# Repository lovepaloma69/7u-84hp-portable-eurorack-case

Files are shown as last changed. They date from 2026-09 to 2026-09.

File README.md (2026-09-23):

# Eurorack 84HP / 7U — Removable Mounting System

Custom, 3D-printed mounting hardware that holds a **7U × 84HP Eurorack frame**
(~440 mm × 311 mm) removably inside a transport / tool case — and, in progress,
inside a wooden rack case. Everything is modeled parametrically in **OpenSCAD**
and verified against the real frame geometry with **trimesh** cross-sections
(no "just print and see" — parts are checked against measured geometry first).

**Designed to fit:** the **RGC Cases 170/48H184** polypropylene case —
<https://rgcases.com/cases-in-polypropylene/170-48h184.html> — which this whole
mounting system is dimensioned around.

> This project is an **accessory** built on top of **kowend's** open Eurorack
> case design (see [Credits & Source](#credits--source)). This repository
> contains **only my own original work** — brackets, rails/profiles, spacer,
> snap latch, clip and holders. It does **not** redistribute kowend's STL / CAD
> / image files; get those from the original project.

## Components

| File | Part | Notes |
|---|---|---|
| `openscad/bracket.scad` | Rail bracket, split into 3 printable segments | References kowend's body STL at build time (see [Setup](#setup--build)) — the STL is not shipped here |
| `openscad/case_holder.scad` | Short-wall rails/profiles, snap latch, flex clip | Firm side (rigid snap, wide neck) + release side (support-only + flex-arm profiles) |
| `openscad/spacer.scad` | Long-wall spacer | 100 × 11 × 11 mm strip; fills the gap between the cover underside and the rail |
| `openscad/wood_holder.scad` | Wooden-case holder | Work in progress |
| `openscad/assembly_explainer.scad`, `openscad/install_context_preview.scad` | Assembly / install visualizations | |
| `analysis/*.py` | Geometry analysis (trimesh + matplotlib) | Cross-sections & measurements used to fit the parts |

## Printed parts (`openscad/export/`)

Ready-to-print STLs for the **original** parts:
`profil*.stl`, `spacer.stl`, `wood_holder.stl`, `flex_clip.stl`.

The **bracket segments** are derived from kowend's model and are therefore
**not** included — regenerate them from `bracket.scad` after obtaining kowend's
STL (see below).

## Setup / Build

1. Install **OpenSCAD** (tested with 2021.01).
2. `bracket.scad` imports kowend's body geometry. Download the corresponding
   STL from the [original project](https://github.com/kowend/Eurorack_84HP_7U_case)
   and place it at:
   ```
   printables/variant1/variant1_body0_local.stl
   ```
3. Export a part, e.g. the toothed profile:
   ```bash
   openscad -D render_part=1 -D with_teeth=true \
     -o export/profil_zaehne.stl case_holder.scad
   ```
4. Verify a part's real dimensions (optional):
   ```bash
   python -c "import trimesh; m=trimesh.load('export/spacer.stl'); print(m.bounds[1]-m.bounds[0])"
   ```

## Print settings

- **Printer:** Bambu Lab A1 Mini
- **Material:** PETG
- **Orientation matters** for the flexing/snap features: the snap latch uses a
  *rigid* arm with a wide neck (push-to-open by tilting the frame flange), and
  the flex clip prints **upright** so it flexes in-plane rather than across
  layer lines. Teeth print flat (across layers) for strength.

## Contributing

**Collaboration and further development of the design are explicitly welcome!**
Feel free to open an [issue](../../issues) for ideas, problems or measurements,
or send a [pull request](../../pulls) with improvements, new variants or
adaptations to other cases. Remixes and forks are encouraged — within the
non-commercial terms of the license below.

## Credits & Source

Frame and case design: **kowend — _Eurorack 84HP 7U case_** —
<https://github.com/kowend/Eurorack_84HP_7U_case>

This project is a derivative *accessory* for that frame. All frame CAD, STL and
image files belong to kowend and are intentionally **not** included in this
repository — please obtain them from the link above.

## License

The original files in this repository are licensed under
**Creative Commons Attribution-NonCommercial 4.0 International (CC BY-NC 4.0)**
(see [`LICENSE`](LICENSE)). You are free to use, modify and further develop the
work and share your versions — **as long as you give credit and do not use it
for commercial purposes**.

This covers *my* files only. The underlying Eurorack frame is kowend's work and
is not included here; refer to the
[original project](https://github.com/kowend/Eurorack_84HP_7U_case) for its
terms.

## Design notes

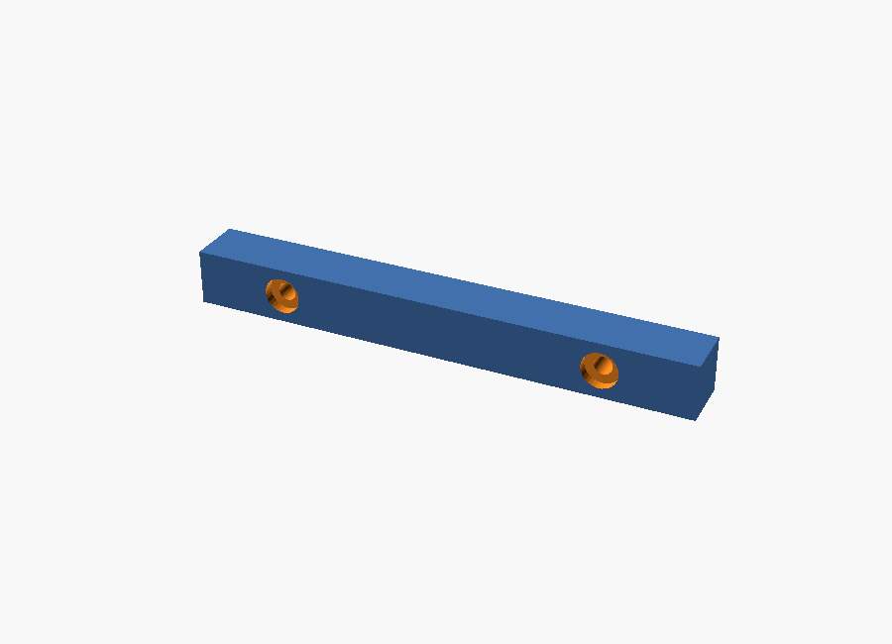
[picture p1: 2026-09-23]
openscad/export/spacer_preview.png

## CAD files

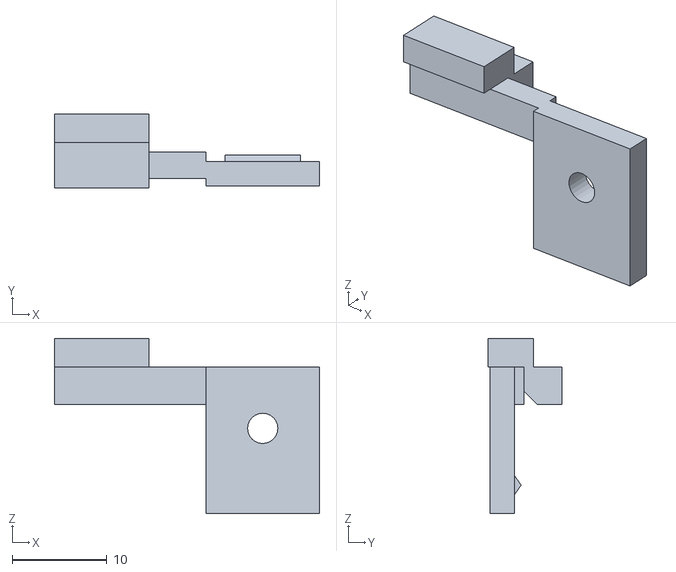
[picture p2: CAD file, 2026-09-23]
openscad/export/flex_clip.stl
28.0 x 7.80 x 18.5

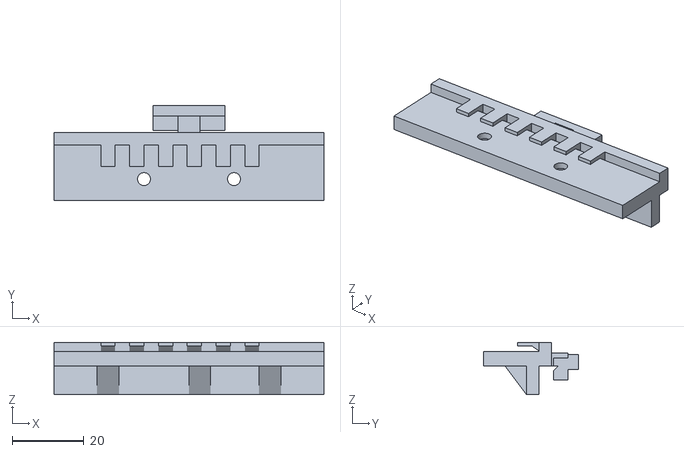
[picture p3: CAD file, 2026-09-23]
openscad/export/profil2_zaehne.stl
75.0 x 26.5 x 14.5

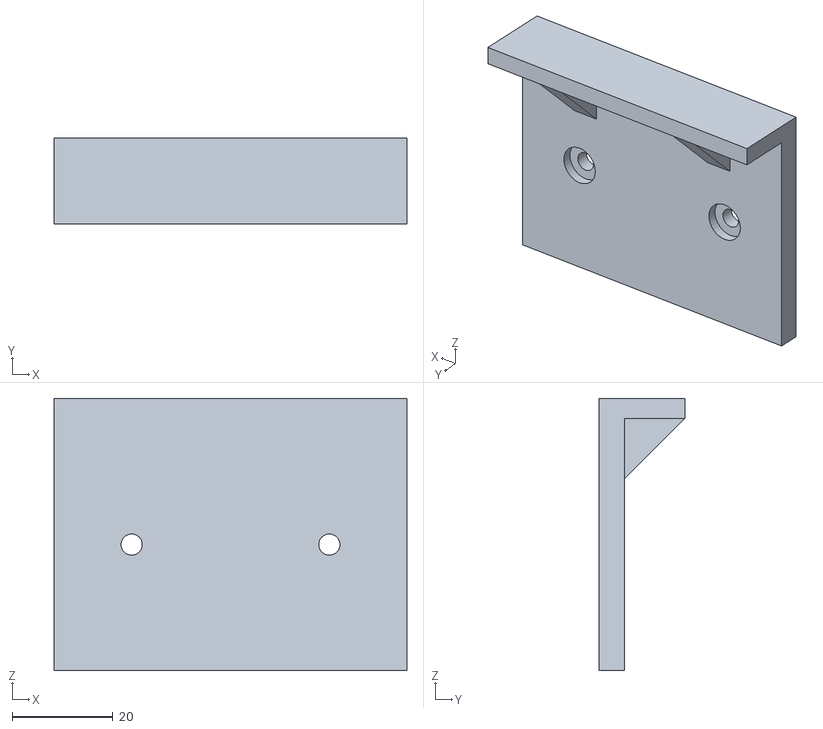
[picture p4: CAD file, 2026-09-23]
openscad/export/wood_holder.stl
70.0 x 17.0 x 54.0

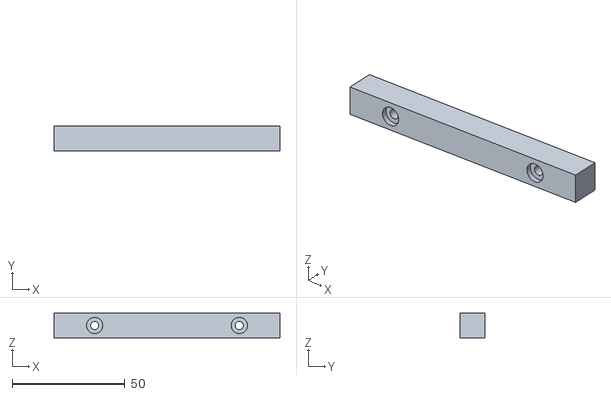
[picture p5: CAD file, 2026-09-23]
openscad/export/spacer.stl
100.0 x 11.0 x 11.0

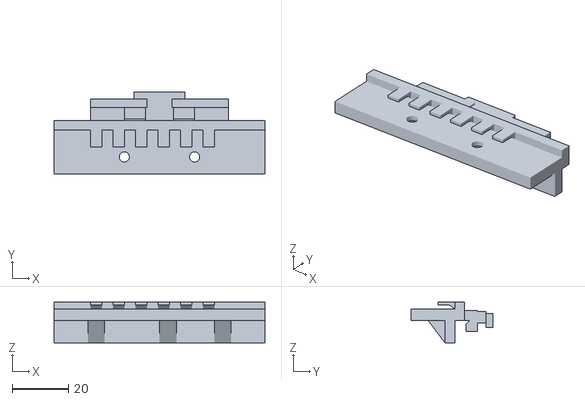
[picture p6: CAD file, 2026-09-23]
openscad/export/profil1_griff.stl
75.0 x 29.0 x 14.5

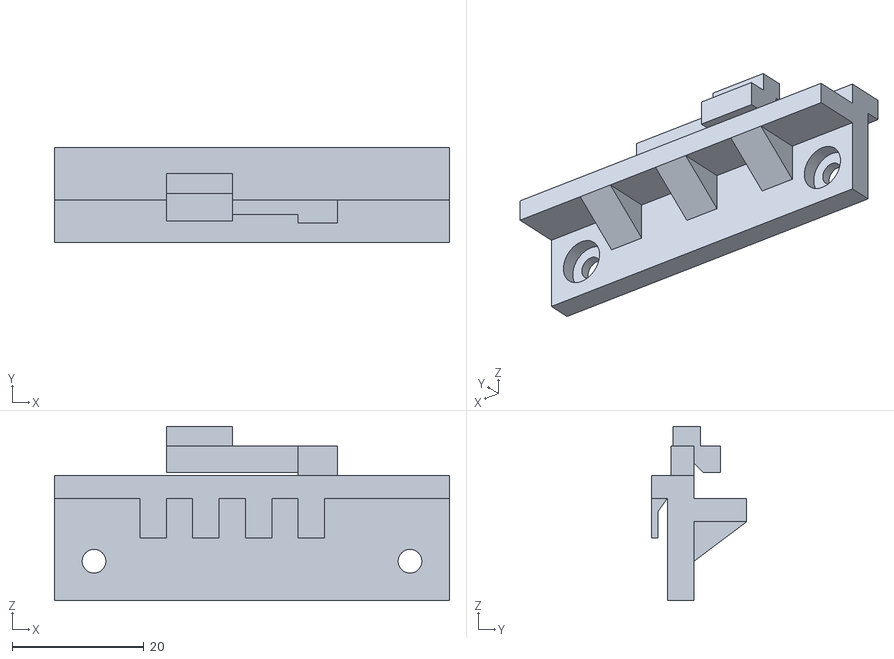
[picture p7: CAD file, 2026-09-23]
openscad/export/profil_B_flexmitte.stl
60.0 x 14.5 x 26.5

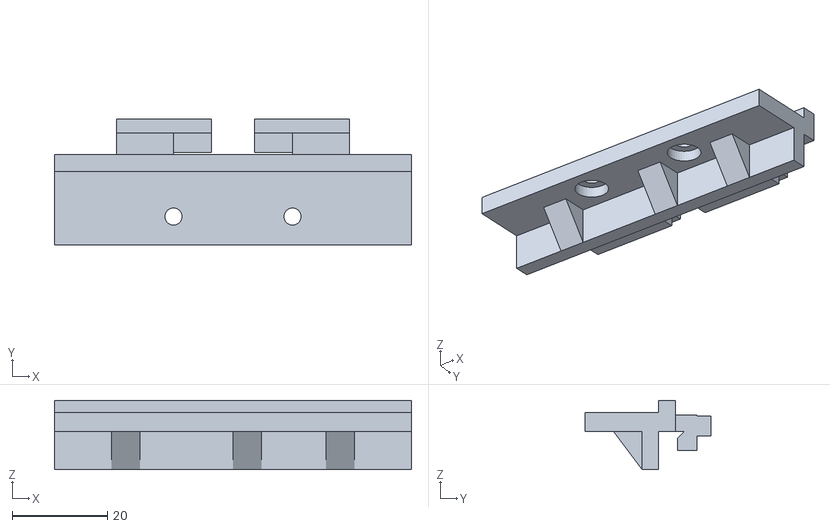
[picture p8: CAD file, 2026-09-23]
openscad/export/profil.stl
75.0 x 26.5 x 14.5

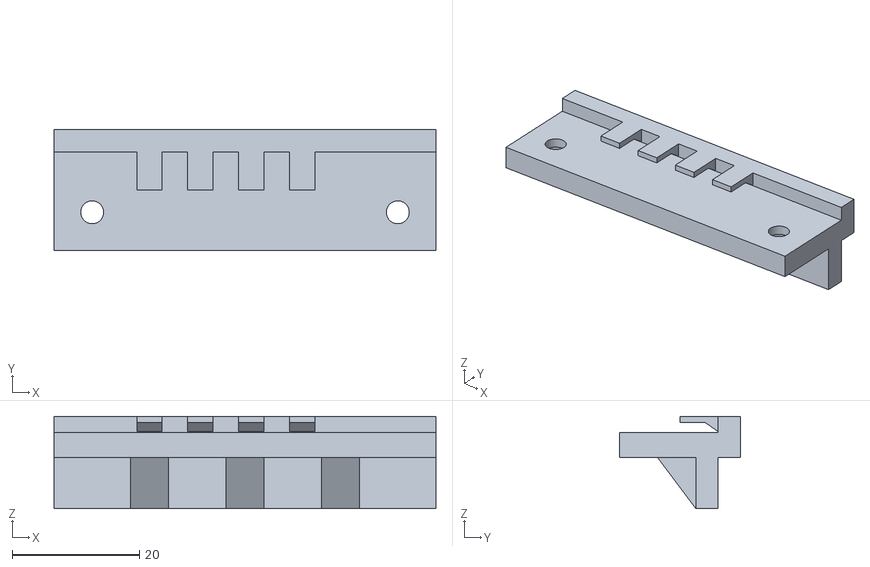
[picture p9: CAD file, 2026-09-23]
openscad/export/profil_B_flach.stl
60.0 x 19.0 x 14.5

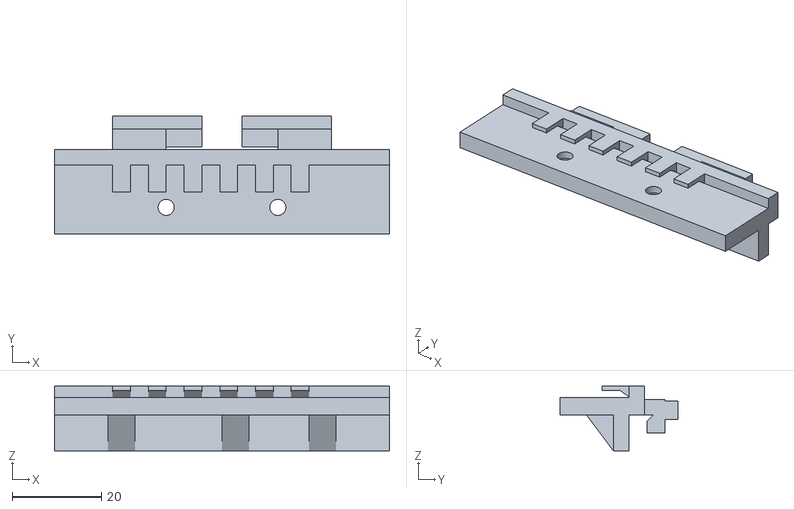
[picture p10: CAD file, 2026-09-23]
openscad/export/profil_zaehne.stl
75.0 x 26.5 x 14.5

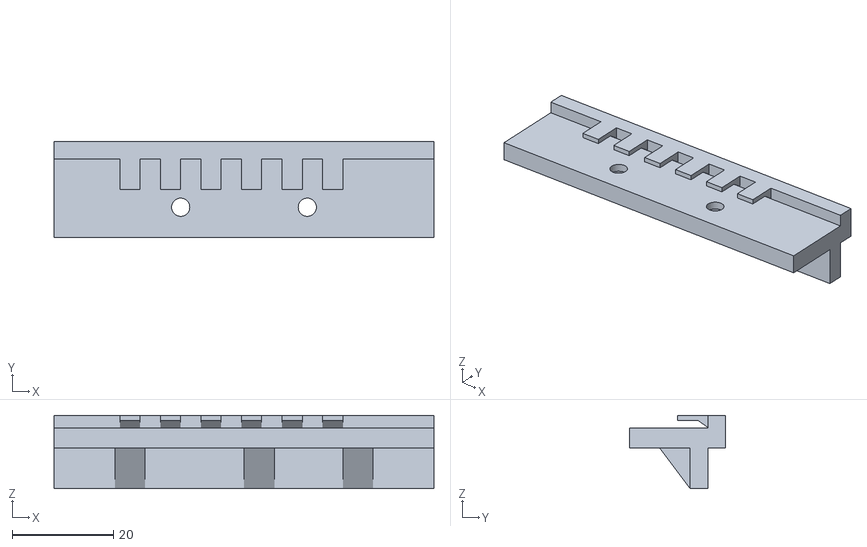
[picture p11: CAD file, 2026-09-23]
openscad/export/profil_A_auflage.stl
75.0 x 19.0 x 14.5

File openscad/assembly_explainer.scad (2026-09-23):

// ======================================================================
// assembly_explainer.scad -- NUR Veranschaulichung, kein Druckteil.
// Zeigt: Profil bleibt FEST im Koffer, der Rahmen (Bracket+Module) liegt
// nur auf und wird komplett nach oben herausgehoben. KEIN Fang, kein Riegel.
// explode=1 hebt den Rahmen heraus, damit die Trennung sichtbar ist.
// ======================================================================
$fn = 32;
explode = 0;      // 0 = eingesetzt, 1 = Rahmen herausgehoben
L = 70;
lift = explode * 55;   // wie weit der Rahmen angehoben gezeigt wird

// ---- KOFFERWAND + Kante (FEST) ----
color("#bdbbb4") {
    translate([-L/2, -6, 0]) cube([L, 6, 67]);       // untere Wand
    translate([-L/2, -6, 67]) cube([L, 3, 13]);      // obere Wand (Stufe=Kante bei 67)
}
color("#c0435a") translate([-L/2, -3, 66.6]) cube([L, 3, 0.5]);  // Kante markiert

// ---- PROFIL (FEST im Koffer: Auflage-Schiene) ----
color("#3d7ea6") {
    translate([-L/2, 0, 48]) cube([L, 4, 22]);          // Rueckwand
    translate([-L/2, -2.5, 63.5]) cube([L, 6.5, 6.5]);  // Nase auf der Kante
    translate([-L/2, 4, 66.5]) cube([L, 8, 3.5]);       // Auflage (Oberkante z=70)
}
color("#333") translate([0, -7, 58]) rotate([-90,0,0]) cylinder(d=3.4, h=6);  // Schraube-Andeutung

// ---- RAHMEN (ENTNEHMBAR: Bracket + Flansch + Module) ----
color("#7ec4e8") translate([-L/2, 3, 70 + lift]) cube([L, 11, 4]);   // Auflage-Flansch
color("#6a6a6a") translate([-L/2, 12, 40 + lift]) cube([L, 8, 30]);  // Bracket
color("#e6cfa8") translate([-L/2+3, 20, 20 + lift]) cube([L-6, 40, 50]); // Module

// ---- Pfeil "herausheben" ----
if (explode == 1)
    color("#2e7d32") {
        translate([0, 20, 74]) cylinder(d=4, h=42);
        translate([0, 20, 116]) cylinder(d1=9, d2=0, h=9);
    }

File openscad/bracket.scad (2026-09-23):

// ======================================================================
// Eurorack 84HP Top-Bracket - segmentiert fuer Bambu Lab A1 Mini
// + Klickverschluss fuer Werkzeugkoffer-Entnahme
//
// Basis: kowend/Eurorack_84HP_7U_case, printables/variant1/variant1_top_bracket.stl
// Nachgebaut als echtes parametrisches Modell (kein STL-Import), damit
// Segmentierung und Klickverschluss sauber integriert werden koennen.
//
// KORRIGIERTE VERSION (2. Durchgang) nach Nutzer-Feedback anhand von
// Fotos des echten Aufbaus:
//   - Das Rack ist ein 7U-Format: 2 Reihen 3U + 1 Reihe 1U (mittig
//     zwischen den beiden 3U-Reihen), macht 3 Reihen x 2 Schienen
//     (oben+unten) = 6 Schienen. Die 6 vermessenen Loecher aus der
//     Original-STL sind GENAU diese 6 Schienen-Positionen (nicht wie in
//     der ersten Version angenommen 6 gleichmaessig verteilte Positionen
//     UND zusaetzlich 6 getrennte Wandschrauben). Reales Muster (siehe
//     ../analysis/06_find_rail_pairs.py, 07_plot_zmax_profile.py):
//       Reihe A oben (3U)  Y=  4.94   -> Abstand 122.8mm (3U) ->
//       Reihe A unten (3U) Y=127.73   -> Abstand  11.4mm (Reihen-Luecke) ->
//       Reihe B oben (1U)  Y=139.15   -> Abstand  32.9mm (1U) ->
//       Reihe B unten (1U) Y=172.10   -> Abstand  11.4mm (Reihen-Luecke) ->
//       Reihe C oben (3U)  Y=183.54   -> Abstand 123.0mm (3U) ->
//       Reihe C unten (3U) Y=306.51
//   - Das Bracket wird VERTIKAL an die Stirnwand des Koffers geschraubt
//     (nicht liegend auf dem Boden wie in der ersten Version). Die 6
//     Schienen-Positionen sind bei installiertem Bracket also senkrecht
//     uebereinander gestapelt, die Schienen ragen waagerecht in den
//     Koffer hinein. Zusaetzlich zu den 6 Schienen-Befestigungen braucht
//     das Bracket EIGENE Wandmontage-Schrauben (3 Stueck, je eine in der
//     Mitte jeder Reihe, siehe wall_mount_positions) - die urspruengliche
//     Version hat faelschlich die Schienen-Loecher dafuer benutzt.
//   - Sockel + Rastarm sitzen nur an EINEM Ende (unten, am Wand/Boden-
//     Uebergang) und werden an die Kofferwand geschraubt, nicht an den
//     Boden. Jedes der zwei Brackets (links/rechts an den Schienen-
//     Enden) hat genau EINEN Rastarm; "beide Rastarme druecken" bezieht
//     sich auf die zwei separaten Brackets, nicht zwei Arme an einem
//     Bracket.
//   - Schienen-Befestigung (4. Durchgang): mehrere Ansaetze verworfen
//     (Kammzaehne direkt in der Spange, separate Kammklammer nach
//     Original-STL-Massen, T-Nutenstein mit Schraube). Nutzerfotos vom
//     echten Original-Bracket + der Schienen-Stirnseite (mit markierten
//     Gegenstuecken) haben die Mechanik endgueltig geklaert: reiner
//     Formschluss per Zusammenstecken, KEINE Schraube. Pro Rail-Position
//     ein T-Stueck (Steg+Querbalken, steckt in eine Tasche der Schiene)
//     und ein Gabel-Zinken-Paar (umfasst einen duennen Schienensteg),
//     direkt in die Spange integriert (rail_connector()-Modul). Masse
//     aus Fotos geschaetzt - unbedingt an einem Testsegment gegen die
//     echte Schiene pruefen, bevor alle 6 final gedruckt werden.
//
// Koordinatensystem im MODELLRAUM (nicht Druckausrichtung!):
//   X = Laengsachse der Spange, 0 .. bracket_total_length. Bei
//       installiertem Bracket ist dies die VERTIKALE Achse (X=0 = unten
//       am Sockel, X=bracket_total_length = oben).
//   Y = Wandstaerke/Dicke,      0 .. bracket_thickness (an Verbindungs-
//       stellen lokal auf joint_boss_thickness verstaerkt). Y=0 ist die
//       Seite, aus der die Schienen herausragen (in den Koffer hinein);
//       Y=bracket_thickness liegt gegen die Kofferwand.
//   Z = Profilhoehe,            0 .. bracket_height
// Fuer den 3D-Druck wird jedes Segment beim Export separat gekippt, so
// dass die Trennebene (Stossflaeche zum Nachbarsegment) flach auf dem
// Druckbett liegt (print_orientation()-Modul weiter unten).
// ======================================================================

$fn = 48;

// ---------------------------------------------------------------------
// 1) GRUNDMASSE DER SPANGE (Schritt 1, aus STL-Vermessung + Nutzer-Korrektur)
// ---------------------------------------------------------------------
bracket_total_length  = 311.25; // gemessen (Koerper 0, Y-Achse im Original-STL)
bracket_thickness     = 8;      // gemessen (Koerper 0, X-Achse im Original-STL)
bracket_height        = 30;     // gemessen ~30.36mm (Koerper 0, Z-Achse im Original-STL), gerundet

// Reale Schienen-Positionen: 3 Reihen (3U, 1U, 3U), je 2 Schienen
// (oben+unten) = 6 Positionen insgesamt. Werte gemessen aus der
// Original-STL (siehe Kommentar oben), als Formel ausgedrueckt statt
// hartcodiert, damit sich z.B. rail_spacing_1u leicht anpassen laesst,
// falls die reale Schiene ein anderes Mass hat.
rail_row_start   = 4.94;    // Position der obersten Schiene (Reihe A oben)
rail_spacing_3u  = 122.88;  // Abstand oben<->unten-Schiene EINER 3U-Reihe
rail_spacing_1u  = 32.95;   // Abstand oben<->unten-Schiene der 1U-Reihe
inter_row_gap    = 11.43;   // Luecke zwischen unterer Schiene einer Reihe
                             // und oberer Schiene der naechsten Reihe

rail_positions = [
    rail_row_start,                                                                  // Reihe A oben (3U)
    rail_row_start + rail_spacing_3u,                                                // Reihe A unten (3U)
    rail_row_start + rail_spacing_3u + inter_row_gap,                                // Reihe B oben (1U)
    rail_row_start + rail_spacing_3u + inter_row_gap + rail_spacing_1u,              // Reihe B unten (1U)
    rail_row_start + rail_spacing_3u + inter_row_gap + rail_spacing_1u + inter_row_gap,               // Reihe C oben (3U)
    rail_row_start + rail_spacing_3u + inter_row_gap + rail_spacing_1u + inter_row_gap + rail_spacing_3u, // Reihe C unten (3U)
];
rail_count = len(rail_positions);

// ---------------------------------------------------------------------
// SCHIENEN-BEFESTIGUNG: T-Stueck + Gabel-Zinken (5. Durchgang - ECHTE
// STL-Geometrie statt geschaetztes Zusatzteil)
// ---------------------------------------------------------------------
// full_bar_cut() importiert jetzt Koerper 0 aus variant1_top_bracket.stl
// direkt (s.u.), statt die Spange per cube() nachzubauen. Das bedeutet:
// das T-Stueck+Gabel-Zinken-Paar an jeder der 6 rail_positions ist BEREITS
// in dieser importierten Geometrie enthalten (im Original-STL nativ
// vorhanden) - es muss nicht mehr separat modelliert/geschaetzt werden.
// Per Fein-Scan (analysis/, X-Aufloesung 0.05-0.1mm, siehe dortige
// Skripte) direkt aus der STL vermessen und gegen alle 6 rail_positions
// bestaetigt (Abweichung < 1mm zu jeder Position):
//   Boss-Breite je Position:      ~8.4-8.5mm
//   T-Stueck (oberes Merkmal):    Z~21.5-26 (Hoehe ~4.5mm), Breite ~6.1mm,
//                                 ragt bis Y=0 (voll, 5mm ueber Basiswand)
//   Gabel-Zinken (unteres Merkmal): Z=0-11.2mm (Hoehe ~11.2mm), zwei
//                                 ungleich breite Zinken (~2.0mm und
//                                 ~3.9mm) mit ~2.6mm Spalt dazwischen,
//                                 beide bis Y=0 ragend
// Vom Nutzer am Original-Bracket-Foto bestaetigt ("Du hast es endlich!").
// Die vorherigen rail_tpiece_*/rail_fork_*-Parameter und das rail_connector()-
// Modul (geschaetzte Nachbildung) sind damit obsolet und entfernt.

// Eigene Wandmontage-Schrauben (3 Stueck, je eine mittig in jeder Reihe -
// getrennt von den 6 Schienen-Positionen, s.o.). Sitzen in der freien
// Flaeche zwischen der oberen und unteren Schiene jeder Reihe (dort ist
// bei einer einzelnen Spange kein Modul im Weg, siehe Uebersichtsbild).
wall_mount_dia       = 4.5;
wall_mount_positions = [
    (rail_positions[0] + rail_positions[1]) / 2,  // Mitte Reihe A (3U)
    (rail_positions[2] + rail_positions[3]) / 2,  // Mitte Reihe B (1U)
    (rail_positions[4] + rail_positions[5]) / 2,  // Mitte Reihe C (3U)
];

// ---------------------------------------------------------------------
// 2) A1-MINI-BAURAUM & SEGMENTIERUNG
// ---------------------------------------------------------------------
a1_mini_build_volume = 180;               // realer Bauraum A1 Mini (mm)
safety_margin        = 10;                // Sicherheitsabstand (Bett-Rand/Skirt/Brim)
max_print_size        = a1_mini_build_volume - safety_margin; // = 170mm

num_segments = 3; // mindestens 3 gefordert; bei 311.25mm Gesamtlaenge waeren
                   // rechnerisch auch 2 Segmente moeglich (155.6mm < 170mm),
                   // aber die Aufgabenstellung verlangt explizit >= 3.
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

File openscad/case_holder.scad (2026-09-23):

// ======================================================================
// case_holder.scad  -- AUFLAGE-SCHIENE ("Profil") + SCHIEBE-RIEGEL
//
// Bleibt FEST im Koffer (an einer kurzen Wand). Traegt den entnehmbaren
// Rahmen (Bracket+Schienen+Module), der AUFLIEGT (Flansch auf der Schiene)
// und nach oben herausgehoben wird.
//
// Halt im Koffer:
//   - Nase liegt auf der internen Kante (13 mm unter dem Rand, 2-3 mm tief)
//   - 2 Schrauben waagerecht in die Kofferwand (B)
//   - OPTIONAL: Einhaengezaehne (with_teeth) in die Wand-Rillen (<=1 mm
//     dick, <=2 mm lang) - Variante zum Ausprobieren.
//   Bleibt komplett unter dem Dichtrand (Deckel schliesst).
//
// SICHERUNG (Schiebe-Riegel, eigenes Druckteil):
//   Nach dem Einlegen des Rahmens wird der Riegel von oben nach INNEN
//   geschoben; sein Balken legt sich ueber die Oberkante des Bracket-
//   Flansches (z=74) -> Rahmen kann nicht mehr hoch. Zurueckschieben =
//   offen. Gefuehrt zwischen zwei L-Schienen (greifen ueber die Riegel-
//   kanten und halten ihn nieder); ein mittiger Griff steht ZWISCHEN den
//   Schienen nach oben und ist von oben mit dem Finger bedienbar. Alles
//   bleibt unter dem Dichtrand (80 mm).
//
// Koordinaten (Koffer-Einbaulage):
//   X = entlang der kurzen Wand (Schienen-Laengsrichtung)
//   Y = von der Wand nach innen; Wand-Innenflaeche (untere Wand) bei Y=0
//   Z = senkrecht; Boden=0, interne Kante=67, Dichtrand=80
// ======================================================================
$fn = 40;

// ---- gemessene Koffer-/Rahmen-Werte ----
ledge_z      = 67;    // interne Kante (13 mm unter Rand 80)
rim_z        = 80;    // Dichtrand (tabu darueber)
ledge_lip    = 2.5;   // wie weit die Kante nach aussen vorsteht (2-3 mm)
// Der Rahmen HAENGT jetzt an seiner FRONT-Kante (Flansch am Bracket-Z=0):
// Front zeigt nach oben, Modulkoerper haengen in den Koffer. rest_z ist die
// Auflageflaeche (Flansch-Unterseite). Tiefer als die Kante (67) gesetzt,
// damit die Front ~16 mm unter der Oeffnung liegt -> Luft fuer Kabel/Potis.
rest_z       = 63.5;  // Oberkante Auflage = Unterseite Rahmen-Flansch
flange_top_z = rest_z + 4;  // Oberkante haengender Flansch (=Front) = 67.5
                            //   -> knapp UEBER Kantenhoehe 67: der Hebel liegt
                            //   direkt auf dem Flansch (kein Spiel, haelt fest),
                            //   raeumt aber die Nase (67) beim Schwenken frei.
nose_top_z   = ledge_z;     // Nase reicht auf Kantenhoehe 67 (haengt an der Kante)
flange_y0    = 7;     // Flansch in Y von 7 (aussen) ..
flange_y1    = 15;    //   .. 15 (siehe Passung-Check im Bracket)

// ---- Profil-Masse ----
prof_len       = 75;    // KURZ: 2 je Wand in die freien End-Zonen des Brackets
                        //   (0..86mm und 225..311mm). Die Verstaerkungs-Kloetze an
                        //   den Segment-Stoessen (Sperrzonen 86..122 und 189..225mm)
                        //   reichen bis auf Auflagehoehe -> ein Profil DORT wuerde den
                        //   Rahmen aufbocken. Darum kurz + an die Enden.
web_t          = 4;     // Dicke der Rueckwand (gegen die Kofferwand)
shelf_in       = 8;     // wie weit die Auflage nach innen reicht
shelf_t        = 3.5;   // Dicke der Auflage
web_bot_z      = 48;    // Rueckwand reicht so weit nach unten (fuer Schrauben)
gusset         = 6;     // Dreiecks-Verstaerkung unter der Auflage

// ---- Schrauben (B), waagerecht in die Kofferwand ----
// Eine Reihe TIEF, damit Kopf/Senkung nicht in die Flansch-/Auflage-Ebene
// (>=60) ragt (dort brach der Nutzer eine ueberlappende Kante ab).
screw_d        = 3.6;   screw_head_d = 7.2;   screw_head_t = 2.4;
screw_z        = [ 54 ];   // Kopf 50.4..57.6, klar unter Auflage (60) & Flansch (63.5)

// ---- Einhaengezaehne (optional, Variante) ----
with_teeth   = false;  // true = Zaehne an der Nase, greifen in die Wand-Rillen
tooth_th     = 1.0;    // Spitzen-Dicke (Y) - <= 1 mm (Spitze muss in die Rille);
                       //   Basis ist per Taper dicker -> bricht nicht mehr ab
tooth_len    = 6.0;    // Laenge nach unten (Z) - LANG bleibt (guter Halt, war ok)
tooth_w      = 4.0;    // Breite (X) - groesser
tooth_pitch  = 8;      // Zahn-Abstand (gleich wie vorher)
tooth_base_th= 2.4;    // Dicke (Y) an der Wurzel (Taper von 1 mm Spitze -> hier)

// ---- SCHNAPP-/KLICK-Verschluss (Sicherung) ----
// Biegsame Rast-Zunge am Profil: HOCH in Z (steif -> haelt den Flansch nieder,
// auch bei Erschuetterung), aber DUENN in Y (biegt seitlich zum Loesen). Der
// Haken oben rastet ueber die Flansch-Oberkante; eine Einlauf-Schraege laesst
// die Zunge beim Einlegen automatisch wegfedern und dann einschnappen.
// Loesen: Griff-Steg zur Wand druecken, Rahmen hoch. Optionale Transport-
// Schraube (with_tscrew) klemmt die Zunge zusaetzlich fest.
with_riegel  = true;
snap_n       = 2;             // Zungen je Profil
snap_x       = 17;            // |X|-Position der Zungen
snap_len     = 30;           // Zungen-Laenge (X)
snap_yt      = 2.2;          // Zungen-Dicke (Y) - die federnde Zunge an der Wand
snap_y       = 1.8;          // Zunge/Saeule GANZ an die Wand (Y=1.8..4.0, ueber die
                             //   Rueckwand). NICHTS auf der Auflage (Y>=4) -> Bracket flach.
snap_z0      = flange_top_z; // 67.5 Arm-Unterkante = Flansch-Oberkante
snap_z1      = snap_z0 + 4;  // 71.5
hook_reach   = 4.0;          // Arm bis Y=8 -> ~1 mm Ueberdeckung ueber die Flansch-Kante (7)
hook_h       = 4.0;          // Arm VOLL HOCH (war 2.2 duenne Lippe -> brach): massiver
                             //   Balken z=67.5..71.5, biegt/bricht nicht mehr
arm_w        = 20;           // Arm-BREITE (X) - war 8, jetzt richtig breit (viel Platz da)
anchor_w     = 12;           // BREITE der Verbindung/Hals (X), womit der Arm am Profil
                             //   sitzt - >= halbe Arm-Breite (war nur 4 -> Arm brach ab)
single_arm   = false;        // false = 2 Arme (FESTE Seite); true = 1 Arm mittig (LOESE-Seite)
neck_single  = 6;            // Anker-Breite der Loese-Seite (halb so breit)
flex_len     = 26;           // Laenge der waagerechten Feder-Zunge (X) = Federweg
flex_w       = 10;           // Breite von Hook/Griff (X) der Feder-Zunge

// ---- SEPARATER Feder-CLIP (Loese-Seite): Profil B wird FLACH mit Zaehnen
//   gedruckt (Zaehne stark) + Schlitz; der Clip steckt hinein und wird AUFRECHT
//   einzeln gedruckt -> die Feder-Zunge biegt in der Layer-Ebene = bruchfest.
with_clipslot = false;       // true = Schlitz fuer den Clip in die Rueckwand (Profil B flach)
clip_len      = 28;          // Gesamtlaenge Clip (X)
clip_foot_w   = 12;          // Fuss-Breite (X), steckt im Schlitz
clip_foot_t   = 2.6;         // Fuss-Dicke (Y)
clip_yt       = 2.8;         // Zungen-Dicke (Y) - federt, aber robust (aufrecht = Layer-Ebene)
clip_foot_z0  = web_bot_z + 8;  // Fuss-Unterkante (steckt bis hier runter im Schlitz)
clip_barb_h   = 0.7;            // Ueberstand der Schnapp-Nase (Rast gegen Herausziehen)
clip_barb_z0  = clip_foot_z0 + 2;  // Nase sitzt hier (rastet in den Schlitz-Recess)
clip_screw_d  = 3.2;            // optionales Schraubloch (selbstschneidend, Transport-Sicherung)
arm_count    = 2;            // 2 = Profil 1 (FEST, 2 Arme); 1 = Profil 2 (FEDERND, 1 Arm mittig)
                             //   Profil 2: mit -D arm_count=1 -D anchor_w=6 exportieren
with_grip    = false;        // Profil-1-Griff-Variante: zentraler Hebel-Steg nach OBEN
                             //   (Modul-Richtung) zum Rauskippen. Mit -D with_grip=true
grip_top_z   = 77;           // Oberkante Griff-Steg (unter Dichtrand 80)
grip_z       = snap_z1 + 3;  // 74.5 Griff-Steg-Oberkante (unter Rand 80)
snap_slot    = 1.4;          // Spalt hinter/neben der Zunge (Federweg + Druck)
with_tscrew  = false;        // optionale Transport-Schraube (klemmt die Zunge)
tscrew_pilot = 2.6;

render_part = 0;   // 0=Profil+Hebel (offen), 1=Profil druckfertig, 2=Hebel druckfertig,
                   // 3=Kontroll: Profil+Hebel ZU (+Flansch-Attrappe), 4=Draufsicht offen+zu
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

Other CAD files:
openscad/install_context_preview.scad
openscad/spacer.scad
openscad/wood_holder.scad

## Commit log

2026-09-23 Initial public release: removable 84HP/7U Eurorack mounting system
    OpenSCAD sources + printable STLs for the original parts (rails/profiles,
    spacer, snap latch, flex clip, wooden-case holder) and trimesh analysis
    scripts. The bracket derives from kowend's Eurorack case (referenced at
    build time, not redistributed).
    [assembly_explainer.scad, bracket.scad, case_holder.scad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]
2026-09-23 Switch license to CC BY-NC 4.0 (non-commercial)
    Allows using, modifying and further developing the work with attribution,
    but not for commercial purposes.
2026-09-23 Docs: invite collaboration and link the RGC 170/48H184 case
    Add a Contributing section (collaboration and further development welcome)
    and a direct reference to the RGC Cases 170/48H184 the system is built for.
